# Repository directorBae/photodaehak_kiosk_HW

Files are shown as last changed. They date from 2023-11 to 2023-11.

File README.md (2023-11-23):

# photodaehak_kiosk_HW

사진대학 키오스크의 모델링 파일, 부품 규격 및 견적 등 키오스크 제작에 필요했던 자료들이 정리되어 있습니다.
모델링은 Autodesk사의 Fusion 360을 통해 진행했으며, 해당 모델링 이후 원목 재질로 키오스크를 구성하였습니다.
브라켓, 너트와 볼트 등 규격에 주의하여 작업했으며
모니터, 프린터기 등 키오스크에 들어갈 부품들 간의 조립, 무게중심 및 강체 시뮬레이션 등을 진행했습니다.

It summarizes the materials needed to manufacture the kiosk, such as modeling files, parts specifications, and estimates of the kiosk at the University of Photography.
The modeling was conducted through Autodesk's Fusion 360, and the kiosk was composed of wood after the modeling.
We worked with caution on specifications such as brackets, nuts, and bolts
We assembled parts for kiosks such as monitors and printers, and simulated center of gravity and rigid bodies.

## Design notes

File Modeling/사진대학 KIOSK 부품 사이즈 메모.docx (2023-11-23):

사진대학 유니캠퍼스 KIOSK 부품 사이즈 메모

for modeling

터치 모니터

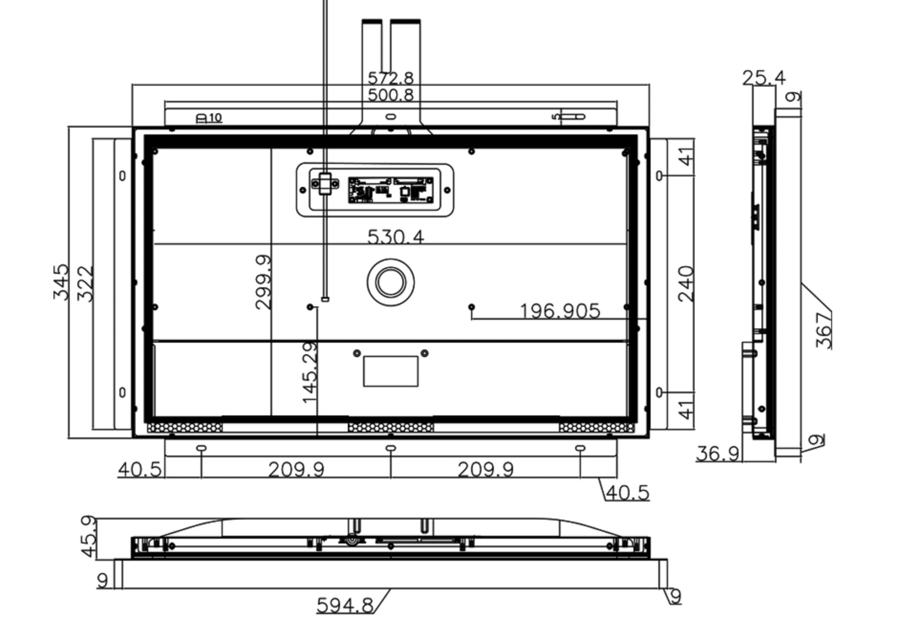
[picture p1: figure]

프린터

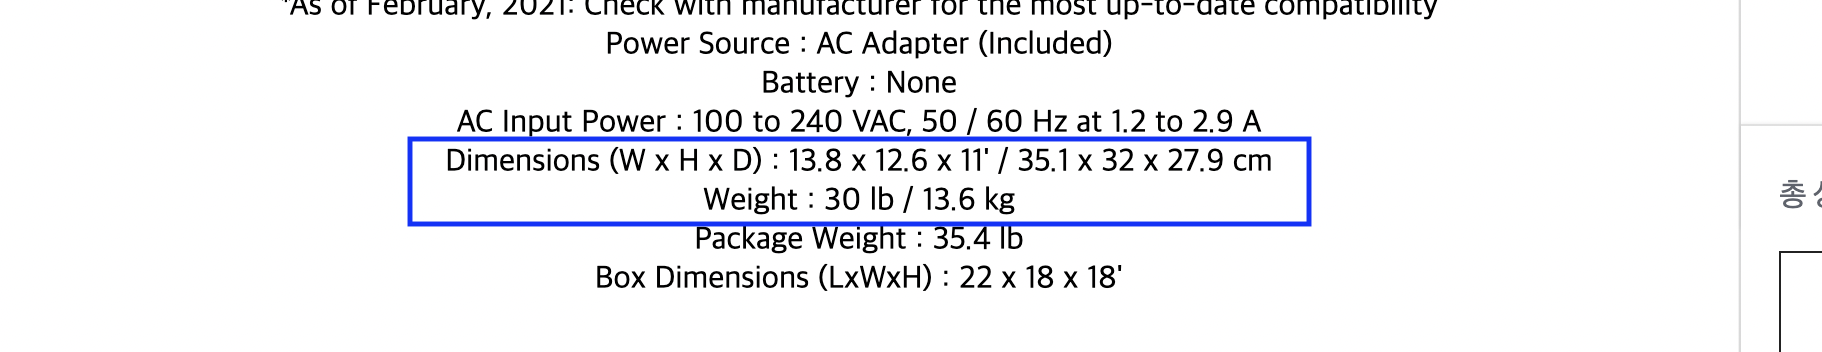
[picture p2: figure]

컴퓨터 본체

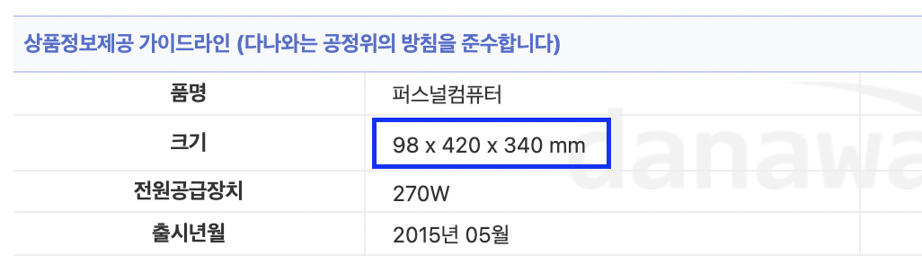
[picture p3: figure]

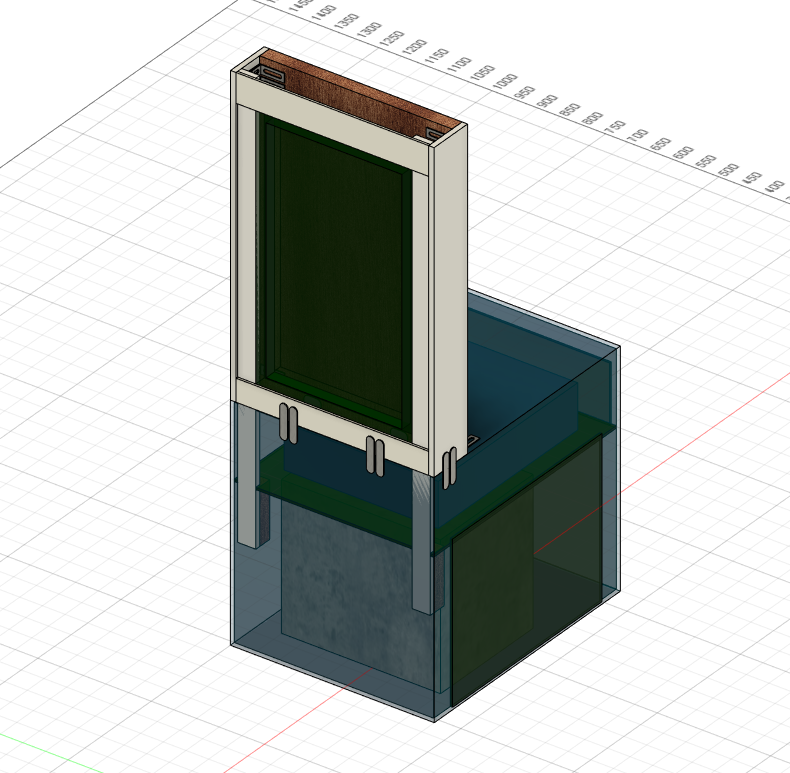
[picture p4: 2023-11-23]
화면 캡처 2023-11-23 235442.png

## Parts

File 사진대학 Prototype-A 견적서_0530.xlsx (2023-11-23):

인화기 KIOSK 견적서 |  |  |  |  |  |  | 총계(배송비 VAT 모두 포함)
 |  |  |  |  |  |  | 2270570
사용처 | 상품명 | 1개가격 | 개수 | 총가격(배송비, VAT 제외) | 구매처 링크 | 부품명 | 구매 옵션 | 배송비 | VAT | 배송비+VAT | 구매처: | 배송 완료 여부
KIOSK | 대성 ViewSync DST240-VF 정전식 터치 오픈프레임 블랙 터치모니터 | 380550 | 1 | 380550 | http://item.gmarket.co.kr/DetailView/Item.asp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 | 터치 가능 모니터 | 옵션 1 | 0 | 0 | 0 | 지마켓 | 결제완료
KIOSK | 해외 DS RX1HS DNP DS RX1HS Dye Sublimation Printer 52 | 1303000 | 1 | 1303000 | http://itempage3.auction.co.kr/DetailView.aspx?ItemNo=C714715134&frm3=V2 | 프린터 |  | 0 | 0 | 0 | 옥션
KIOSK | 삼성 4세대 슬림 GT520 (업무/그래픽용) | 207000 | 1 | 207000 | https://www.coupang.com/vp/products/6731461903?itemId=15686225868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 | 컴퓨터 본체 | i5-4570/8G/SSD240+500 | 0 | 0 | 0 | 쿠팡 | 결제완료
KIOSK | 보쉬 GSR18V-90C 충전드릴 드라이버 5.0Ah 배터리2개 | 334020 | 1 | 334020 | https://www.11st.co.kr/products/5398498998 | 드릴 | [추가] 4.보쉬 Xline 100pcs | 5000 | 0 | 5000 | 11번가
KIOSK | 열선커터기 우드락커터기 포맥스재단 나이프 가열 재단 컷팅 | 41000 | 1 | 41000 | https://smartstore.naver.com/psglobalmarket/products/7905437084 | 포맥스칼 | D | 0 | 0 | 0 | 네이버 스마트스토어
 |  |  |  | 0 |  |  |  |  |  | 0
 |  |  |  | 0 |  |  |  |  |  | 0
총계 |  |  |  | 2265570 |  |  |  |  |  | 5000

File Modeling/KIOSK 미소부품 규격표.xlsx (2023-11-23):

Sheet: 표지
사진대학 KIOSK 미소부품 규격 명세표

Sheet: 규격 명세표
순번 | 부품 종류 | 활용 용도 | 활용 위치 | 세부 종류 | 규격 | 수량 | 비고 | 구매 링크
1 | 브라켓 | 모니터 - 후면 MDF 연결 | 베사브라켓 | 베사브라켓 | 75x75, 10mm in MDF | 1
2 | 나사 | 모니터 - 후면 MDF 연결 | 모니터 나사 | 둥근머리볼트 | M4x14 |  | 1번 구매에 포함
3 | 와셔 | 모니터 - 후면 MDF 연결 | 모니터 나사 와셔 | 평와셔 | M5 |  | 1번 구매에 포함
4 | 나사틀 | 모니터 - 후면 MDF 연결 | 벽면 나사틀 | 나사틀 | M10x60 |  | 1번 구매에 포함
5 | 나사 | 모니터 - 후면 MDF 연결 | 벽면 나사 | 육각볼트 | M4.5x55 |  | 1번 구매에 포함
6 | 와셔 | 모니터 - 후면 MDF 연결 | 벽면 와셔 | 평와셔 | M6 |  | 1번 구매에 포함
7 | 너트 | 모니터 - 후면 MDF 연결 | 벽면 고정너트 | 육각너트 | M10 | 2
8 | 와셔 | 모니터 - 후면 MDF 연결 | 벽면 고정와셔 | 평와셔 | M10 | 2
9 | 브라켓 |  |  | L자 2홀브라켓 | M8, 2T, 20x26/20x52 | 25 |  | https://99mim.com/goods/view?no=27292
10 | 브라켓 |  |  | L자 4홀브라켓 | M4, 0.7T, 18x38/18x38 | 50 |  | https://99mim.com/goods/view?no=25478
11 | 브라켓 |  |  | 평브라켓 | M4.8, 2T, 17x76 | 20 |  | https://99mim.com/goods/view?no=19345
12 | 브라켓 |  |  | L자 2홀브라켓 | M4, 2T, 15x18 | 50 |  | https://99mim.com/goods/view?no=29151
13
14
15
16
17
18
19
20
21
22
23
24
25
26
27
28
29
30
31
32
33

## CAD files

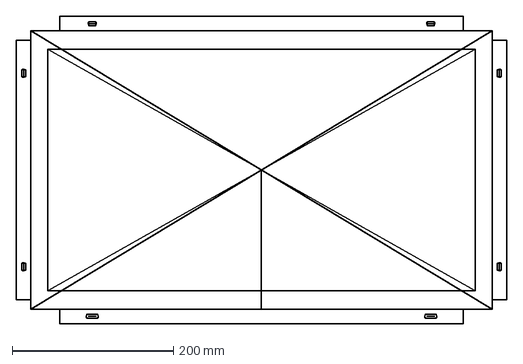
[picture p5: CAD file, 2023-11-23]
Modeling/monitor.dxf
608.0 x 381.0 mm

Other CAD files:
Modeling/KIOSK 모델링 v11.f3d

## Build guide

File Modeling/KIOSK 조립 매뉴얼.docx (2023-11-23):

모니터-베사브라켓-후면MDF합판(30T)

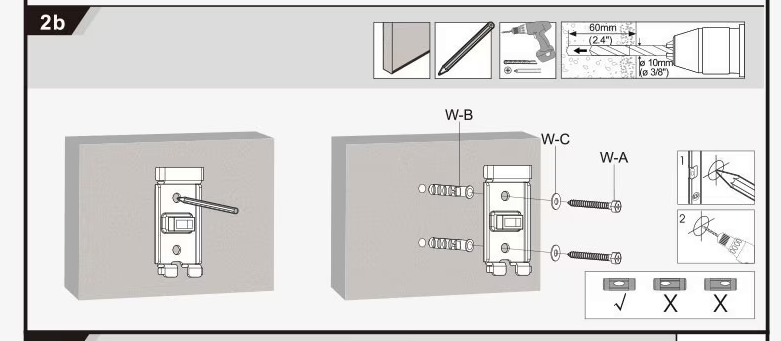
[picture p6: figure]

모니터 고정틀(상단) 전면부 고정

ㄱ자연결(전면-옆면 연결)

브라켓: 9번부품

전면 길쭉한 합판 고정볼트: 10번부품

옆면 짧은 합판(후면 MDF와 연결되는) 고정볼트: 11번부품

너트/와셔: 12,13번부품

두겹 연결(전면 2개판 연결)

고정볼트: 10번부품

너트/와셔: 12,13번부품

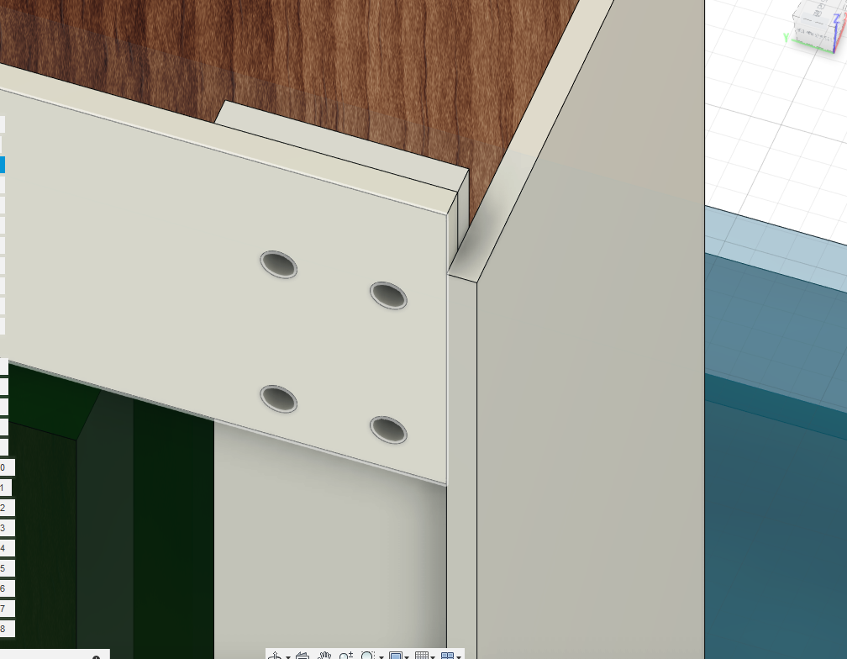
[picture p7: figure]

모니터 고정틀(하단) 전면부 고정

모니터틀 고정용

머신박스 연결용
